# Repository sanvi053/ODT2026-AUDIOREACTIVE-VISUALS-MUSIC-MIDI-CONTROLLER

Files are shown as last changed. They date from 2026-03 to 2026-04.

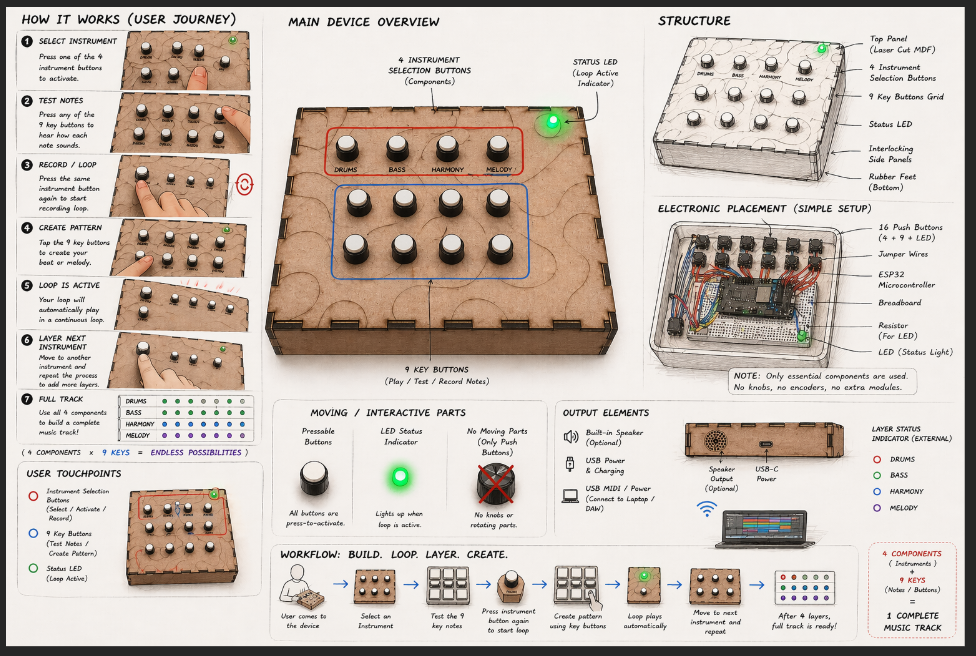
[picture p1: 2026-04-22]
images/Screenshot 2026-04-22 204658.png

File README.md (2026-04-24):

# Open Design and Technology  
## Final Project README

> **Project Weight:** 70%  
> **Team Size:** 2 students  
> **Project Duration:** 4 weeks  
> **Class Time Available:** 6 hours per class  
> **Total Time Available:** 48 effort-hours per team  
> **Project Type:** Playful, interactive, technology-based experience

---

# Before you begin

## Fork and rename this repository
After forking this repository, rename it using the format:

`ODT-2026-TeamName`

### Example
`ODT-2026-PixelWizards`

Do not keep the default repository name.

---

# How to use this README

This file is your team’s **working project document**.

You must keep updating it throughout the 4-week build period.  
By the final review, this README should clearly show:
- your idea,
- your planning,
- your design decisions,
- your technical process,
- your build progress,
- your testing,
- your failures and changes,
- your final outcome.

## Rules
- Fill every section.
- Do not delete headings.
- If something does not apply, write `Not applicable` and explain why.
- Add images, screenshots, sketches, links, and videos wherever useful.
- Update task status and weekly logs regularly.
- Use this file as evidence of process, not only as a final report.

---

# 1. Team Identity

## 1.1 Studio / Group Name
Audio Reactive Music MIDI Controller 

## 1.2 Team Members

| Name | Primary Role | Secondary Role | Strengths Brought to the Project |
|---|---|---|---|
| Manasvi D. | Electronics and Coding  | Physical Presentation  | Circuit Building  |
| Sanvi T. | Software manipulation  | Creating initial testing versions  | Musical understanding ` |

## 1.3 Project Title
Audio Reactive Music MIDI Controller 

## 1.4 One-Line Pitch
A MIDI Controller made from scratch that can help you create music using looping tracks and then see it corresponding to audio reactive visuals.  `

## 1.5 Expanded Project Idea
In 1–2 paragraphs, explain:
- what your project is,
- what kind of playful experience it creates,
- what makes it fun, curious, engaging, strange, satisfying, competitive, or delightful,
- what technologies are involved.

**Response:**  
Our project is an interactive music-making experience where users create and explore their own sound using a custom MIDI controller. They can switch between instruments, layer beats, and experiment with rhythms in an intuitive way, with no prior musical experience needed. The controller interfaces with Ableton Live, enabling real-time sound generation and flexible music creation. 

What makes it engaging is the instant audio-visual feedback: as users build their beats, their music is visualized in real time, making the process both satisfying and immersive. The project combines a custom MIDI controller, Ableton Live for music production, and TouchDesigner for dynamic visuals, blending physical interaction, sound, and visuals into a playful creative system. 

# 2. Philosophy Fit

## 2.1 Experience, Not Social Problem
This module does **not** require your project to solve a large social problem.

You are allowed to build:
- toys,
- games,
- interactive objects,
- playful machines,
- kinetic artifacts,
- humorous devices,
- strange but delightful experiences,
- things that are entertaining to use or watch.

## 2.2 What kind of experience are you creating?
Answer the following:
- What is the experience?
- What do you want the player or participant to feel?
- Why would someone want to try it again?

**Response:**  
This project places the user in the role of a DJ or live music performer, where their beats are paired with dynamic, captivating visuals to create a mini concert experience. It builds an immersive and playful environment where users feel in control of their performance and creative output. The experience encourages them to return, experiment with new beats, and discover how each change transforms the visuals in real time. 

## 2.3 Design Persona
Complete the sentence below:

> We are designing this project as if we are a small creative studio making a **[toy / game / playable object / interactive experience]** for **[children / teens / adults / classmates / exhibition visitors / mixed audience]**.

**Response:**  
We are designing this project as if we were a small design studio making an interactive experience for exhibition visitors to experiment with.  

---

# 3. Inspiration

## 3.1 References
List what inspired the project.

| Source Type | Title / Link | What Inspired You |
|---|---|---|
| Ed Sheeran Looping Pedal Live performances. | `[Link or title]` |Borrowed how he adds different tracks live to create a musical experience  |
|Live Audio-reactive visuals | `[Link or title]` |The act of live music controlling visuals |

## 3.2 Original Twist
What makes your project original?

**Response:**  
Combining live sets with visuals is not a common concept, and we decided to make music looping more accessible to non-professional artists.  

---

# 4. Project Intent

## 4.1 Core Interaction Loop
Describe the main loop of interaction.

Examples:
- press → launch → score → reset
- connect → control → observe → repeat
- turn → trigger → react → repeat
- move object → sensor detects → sound/light response → player reacts

**Response:**  
Press instrument button → Press same button again to activate loop recording → Press the keynotes to create beat → Press another instrument [if you want to add] → Repeat same steps → Once done creating the beat, press instrument buttons to clear recorded beat 

## 4.2 Intended Player / Audience

| Question | Response |
|---|---|
| Who is this for? | Exhibition visitors  |
| Age range | 12+|
| Solo or multiplayer |Solo|
| Expected duration of one round |3-4min|
| What should the player feel? |Immersed, creative, accomplished |
| Is explanation required before use? |Yes|

## 4.3 Player Journey
Describe exactly how a player will use the project.

1. **Approach:**  The player begins in front of a dormant visual display, with a custom music control unit placed on the table. 
2. **Start:** The interaction begins by creating the first looping track.
3. **First Action:** The player selects instruments using dedicated buttons to activate individual tracks.
4. **Main Interaction:** Beats and melodies are built layer by layer, with each track looping continuously in real time.
5. **System Response:** The audio plays and evolves through loops while the visuals dynamically respond and adapt to the sound. 
6. **Win / Lose / End Condition:** The session concludes once the complete music composition is formed, and the visuals fully respond to the final output.
7. **Reset:** A new round begins by clearing all active loops, allowing the user to start a fresh composition. 

## 4.4 Rules of Play
If your project is a game, list the rules clearly.

- `[Rule 1]`
- `[Rule 2]`
- `[Rule 3]`
- `[Rule 4]`

---

# 5. Definition of Success

## 5.1 Definition of “Playable”
Your project will be considered complete only if these conditions are met.

Music track is completed and looping 
The visuals react to the music in real time 

## 5.2 Minimum Viable Version
What is the smallest version of this project that still delivers the core experience?

One instrument track (ex. Piano) sends musical notes through buttons, and a basic visual reacts to them.  

## 5.3 Stretch Features
What features are nice to have but not essential?

Multiple instrument tracks (beyond the base instrument) 
Adding audio effects to beats created, i.e. reverb, delay, auto filter, etc. 
More advanced or detailed visual reactions in Touch Designer 
---

# 6. System Overview

## 6.1 Project Type
Check all that apply.

Electronics-based 
Mechanical 
Sound-based 
Screen/UI-based 
Fabricated structure
Installation / tabletop experience 
Other: Audioreactive Visuals 

## 6.2 High-Level System Description
Explain how the system works in simple terms.

Include:
- input,
- processing,
- output,
- physical structure,
- app interaction if any.

**Response:**  
When the user presses a button on the physical controller, the input is detected through an ESP32 running MicroPython in Thonny, using a BLE Keyboard library. This input is sent as keyboard signals to the computer. In Ableton Live, each sound or function is mapped to specific keyboard keys, so the received input triggers the corresponding instrument or sound. 

The system works on a simple mapping flow: physical button → ESP32 → keyboard signal → Ableton Live → audio output. The result is real-time sound generation based on user interaction 

## 6.3 Input / Output Map

| System Part | Type | What It Does |
|---|---|---|
|ESP32 / Controller | Processing  |Transmits input messages to output components  |
|LED / Sound / Display | Output  |LED- loop recording indicator; Sound- created music track; Display- Visual presentation of music track | 
|Mechanical Assembly  |Physical Action |NA|
---

# 7. Sketches and Visual Planning

## 7.1 Concept Sketch
Add an early sketch of the full idea.

**Insert image below:**  

Example:
```md

```

## 7.2 Labeled Build Sketch
Add a sketch with labels showing:
- structure,
- electronics placement,
- user touch points,
- moving parts,
- output elements.

**Insert image below:**  
`[Upload image and link here]`

## 7.3 Approximate Dimensions

| Dimension | Value |
|---|---|
| Length |9 in.|
| Width |7 in. |
| Height |3 in.|
| Estimated weight |500 gm |

---

# 8. Mechanical Planning

## 8.1 Mechanical Features
Check all that apply.

- [ ] Gears
- [ ] Pulleys
- [ ] Belt drives
- [ ] Linkages
- [ ] Hinges
- [ ] Shafts
- [ ] Springs
- [ ] Bearings
- [ ] Wheels
- [ ] Sliders
- [ ] Levers
- [ ] Not applicable

## 8.2 Mechanical Description
Describe the mechanism and what it is meant to do.

**Response:**  
`[Write here]`

## 8.3 Motion Planning
If something moves, explain:
- what moves,
- what causes the movement,
- how far it moves,
- how fast it moves,
- what could go wrong.

**Response:**  
`[Write here]`

## 8.4 Simulation / CAD / Animation Before Making
If your project includes mechanical motion, document the digital planning before fabrication.

| Tool Used | File / Link | What Was Tested |
|---|---|---|
| `[Fusion 360 / Tinkercad / other]` | `[Link or screenshot]` | `[What did you validate?]` |
| `[Tool]` | `[Link or screenshot]` | `[What did you validate?]` |

## 8.5 Changes After Digital Testing
What changed after the CAD, animation, or simulation stage?

**Response:**  
`[Write here]`

---

# 9. Electronics Planning

## 9.1 Electronics Used

| Component | Quantity | Purpose |
|---|---:|---|
|[ESP32] | 1 |Main controller|
|Push Button| 13 |Controlling the musical notes/beats and initiating/creating the loop|
|LED | 1 |Indicates if the loop recording has started|

## 9.2 Wiring Plan
Describe the main electrical connections.

**Response:**  
Buttons are connected various pins on ESP-32 
LED Bulb connected to ESP32 

## 9.3 Circuit Diagram
Insert a hand-drawn or software-made circuit diagram.

**Insert image below:**  
`[Upload image and link here]`

## 9.4 Power Plan

| Question | Response |
|---|---|
| Power source |USB|
| Voltage required |3V|
| Current concerns |Low power consumption overall, but unstable USB connections or insufficient power supply from some ports may cause intermittent disconnections of the ESP32. |
| Safety concerns |Accidentally soldering buttons incorrectly and damaging ESP-32 |

---

# 10. Software Planning

## 10.1 Software Tools

| Tool / Platform | Purpose |
|---|---|
|MicroPython Thonny |Thonny-Running Code and ESP32 |
|Ableton Live |MIDI controller outputs and instrumental track loop arrangement |
|Touchdesigner |Connecting music track components to visual manipulations |
|Adobe Illustrator |Used to create precise vector design files for laser cutting the MIDI controller setup|
|Rhino |Used to create precise vector design files for laser cutting the MIDI controller setup|

## 10.2 Software Logic
Describe what the code must do.

Include:
- startup behavior,
- input handling,
- sensor reading,
- decision logic,
- output behavior,
- communication logic,
- reset behavior.

**Response:**  
The software logic governs how the controller initializes, processes user inputs, and communicates with external software such as Ableton Live and TouchDesigner. 

Startup Behavior: 
When the system is powered on, the ESP32 initializes all GPIO pins for input (buttons) and output (LEDs). The Bluetooth module is activated, and the device begins advertising itself as a wireless input controller. Default states are assigned to all buttons and LEDs to ensure no unintended signals are sent during initialization. 

Input Handling: 
The system continuously scans the state of each button using a loop. Each button is configured with a pull-up resistor, meaning a press is detected when the signal changes from HIGH to LOW. The current state is compared with the previous state to detect valid press events (edge detection), preventing repeated triggering while a button is held down. 

Decision Logic: 
Based on the detected input, the system determines the appropriate action. For example: 

A single button press triggers a specific key or command.  

Sequential presses (such as first press, second press) are tracked using state variables.  

Conditional logic is used to control LED behavior (e.g., blinking sequence, steady ON state). 
This ensures that each interaction produces a predictable and controlled response.  

Output Behavior: 
Outputs are handled in two ways: 

Digital Output (LEDs): LEDs provide visual feedback based on system state, such as blinking during active phases or remaining ON to indicate a stable state.  

Software Output (Input Signals): The ESP32 sends keyboard/MIDI-like signals via Bluetooth, which are received by Ableton Live to trigger sounds, loops, or effects.  

Communication Logic: 
The controller communicates wirelessly via Bluetooth Low Energy (BLE). Input signals are transmitted as keyboard or MIDI messages. Ableton Live processes these inputs to generate audio, which is then routed internally to TouchDesigner using virtual audio drivers. This enables synchronized audio-visual output. 

Reset Behavior: 
The system resets under two conditions: 

Manual reset (power cycle): All states return to default, and Bluetooth reconnects.  

Logical reset: Certain interaction sequences (e.g., repeated button cycles) reset LED patterns and input states to prevent unintended looping or stuck states.  

This ensures stable operation during continuous use. 

## 10.3 Code Flowchart
Insert a flowchart showing your code logic.

Suggested sequence:
- start,
- initialize,
- wait for input,
- read input,
- decision,
- trigger output,
- repeat or reset,
- error handling.

**Insert image below:**  
`[Upload image and link here]`

## 10.4 Pseudocode
INITIALIZE Bluetooth keyboard with name "ESPMIDIMS" 

INITIALIZE LED as OUTPUT 

INITIALIZE performance buttons (A–L) as INPUT with pull-up resistors 

STORE last state of each performance key as HIGH 

INITIALIZE 4 control buttons as INPUT with pull-up resistors 

STORE last state of each control button as HIGH 

SET control state of each button = 0 

DEFINE control actions as: 

    Button 1 → [q, n, m] 

    Button 2 → [r, 2, 3] 

    Button 3 → [i, 4, 5] 

    Button 4 → [b, 6, 7] 

PRINT "Controller Ready" 

FUNCTION blink_LED: 

    REPEAT 4 times: 

        TURN LED ON 

        WAIT 0.5 seconds 

        TURN LED OFF 

        WAIT 0.5 seconds 

    TURN LED ON (stay ON) 

LOOP forever: 

    IF Bluetooth is connected: 

        // ------------------------- 

        // PERFORMANCE KEYS 

        // ------------------------- 

        FOR each key in performance keys: 

            READ current state 

            IF key is PRESSED (LOW) AND last state was NOT PRESSED (HIGH): 

                SEND corresponding key via Bluetooth 

                WAIT 40 ms 

            UPDATE last state 

        // ------------------------- 

        // CONTROL BUTTONS 

        // ------------------------- 

        FOR each control button (index i): 

            READ current state 

            IF button is PRESSED (LOW) AND last state was HIGH: 

                WAIT 50 ms (debounce) 

                IF still PRESSED: 

                    IF control state == 1: 

                        CALL blink_LED 

                    SELECT action from CONTROL_ACTIONS using control state 

                    SEND action via Bluetooth 

                    UPDATE control state: 

                        (state = (state + 1) mod 3) 

                    PRINT which button and action sent 

                    WAIT 150 ms 

            UPDATE last control state 

    WAIT 20 ms

---

# 11. MIT App Inventor Plan

## 11.1 Is an app part of this project?
- [ ] Yes
- [ ] No

If yes, complete this section.

## 11.2 Why is the app needed?
Explain what the app adds to the experience.

Examples:
- remote control,
- score tracking,
- mode selection,
- personalization,
- triggering effects,
- displaying data.

**Response:**  
`[Write here]`

## 11.3 App Features

| Feature | Purpose |
|---|---|
| `[Bluetooth connect button]` | `[Purpose]` |
| `[Score display]` | `[Purpose]` |
| `[Control button / slider / label]` | `[Purpose]` |

## 11.4 UI Mockup
Insert a sketch or screenshot of the app interface.

**Insert image below:**  
`[Upload image and link here]`

## 11.5 App Screen Flow

1. `[Step 1]`
2. `[Step 2]`
3. `[Step 3]`
4. `[Step 4]`

---

# 12. Bill of Materials

## 12.1 Full BOM

| Item | Quantity | In Kit? | Need to Buy? | Estimated Cost | Material / Spec | Why This Choice? |
|---|---:|---|---|---:|---|---|
| `[ESP32]` | `1` | `Yes` | `No` | `0` | `[Spec]` | `[Reason]` |
|Push Buttons|13|No (not the kind we needed) |Yes|Rs. 400| Not producing click sound when pressed  |Smoother interaction than provided push buttons|
|LED Bulb |1|Yes|0| `[Spec]` | `[Reason]` |
|Jumper Wire|35|No|0| `[Spec]` | `[Reason]` |

## 12.2 Material Justification
Explain why you selected your main materials and components.

Examples:
- Why acrylic instead of cardboard?
- Why MDF instead of 3D print?
- Why servo instead of DC motor?
- Why bearing instead of a plain shaft hole?

**Response:**  
We chose MDF for the base structure because it is strong, stable, and cost-effective compared to 3D printing large parts. It is easier to laser cut for flat structural components and provides good rigidity to hold the electronics securely. 

We used push buttons instead of more complex input components like rotary encoders or touch sensors because they are simple, reliable, and provide clear tactile feedback, making the interaction more intuitive for users. 

## 12.3 Items to Purchase Separately

| Item | Why Needed | Purchase Link | Latest Safe Date to Procure | Status |
|---|---|---|---|---|
|Push Buttons |Push Buttons  | NA (Nimesh Electronics)  |10th March |Received|

## 12.4 Budget Summary

| Budget Item | Estimated Cost |
|---|---:|
| Electronics | Rs. 400|
| Mechanical parts |NA|
| Fabrication materials |NA|
| Purchased extras |NA|
| Contingency |Rs.150|
| **Total** |Rs.550|

## 12.5 Budget Reflection
If your cost is too high, what can be simplified, removed, substituted, or shared?

**Response:**  
NA

---

# 13. Planning the Work

## 13.1 Team Working Agreement
Write how your team will work together.

Include:
- how tasks are divided,
- how decisions are made,
- how progress will be checked,
- what happens if a task is delayed,
- how documentation will be maintained.

**Response:**  
Team Working Strategy 

The project is executed through a collaborative approach where responsibilities are divided based on individual strengths, while still allowing overlap for support and flexibility. 

Task Division: 

Tasks are primarily divided according to expertise. Manasvi leads electronics and coding, focusing on circuit building and implementing the core logic. Sanvi leads software-related work, handling interaction with Ableton Live and TouchDesigner, along with initial testing and musical mapping. 

Both members support each other in secondary roles to ensure continuity and shared understanding of the system. 

Decision Making: 

Decisions are made collaboratively through discussion and testing. Ideas are evaluated based on functionality, user experience, and feasibility. In case of differing opinions, small prototypes or trials are created to test outcomes, and the most effective solution is selected. 

Progress Tracking: 

Progress is monitored through regular check-ins and testing sessions. Each module (electronics, coding, software integration) is tested individually and then combined to evaluate overall system performance. Milestones are set for key stages such as input detection, sound triggering, and audio-visual synchronization. 

Handling Delays: 

If a task is delayed, responsibilities are adjusted temporarily. The support owner assists in completing the pending task to maintain workflow continuity. Simpler alternatives or workarounds are also considered to avoid blocking the overall progress of the project. 

Documentation Maintenance: 

Documentation is primarily managed by Sanvi, with support from Manasvi. All stages of the project, including concept development, circuit design, code logic, and testing outcomes, are recorded regularly. Updates are made alongside development to ensure accuracy and completeness, rather than being compiled at the end. 

## 13.2 Task Breakdown

| Task ID | Task | Owner | Estimated Hours | Deadline | Dependency | Status |
|---|---|---|---:|---|---|---|
| T1 | `[Finalize concept]` | `Sanvi ` | `1 day ` | `7th April ` | `None` | `Finalize which software to use ` |
| T2 | `[Complete BOM]` | `Both ` | `Availabilty of shop timming ` | `10th April` | `T1` | `Placing porter from reliable shop ` |
| T3 | `[Test electronics]` | `Both ` | `24 hrs` | `15th April` | `T1` | `Testing how the electric components work along with code, and software ` |
| T4 | `[Build structure]` | `Both ` | `3 hrs` | `[20th April]` | `T1` | `Make laser cutting file and get it printed and assemble all parts together` |
| T5 | `[Write control code]` | `Manasvi` | `2 hrs` | `17th April` | `T3` | `Compling all libraries and testing code acc to condition required and debugging error ` |
| T6 | `[Integrate system]` | `Both` | `1 h` | `19th April` | `T4, T5` | `Having a checklist of steps to verify if all steps have been achieved in correct order ` |
| T7 | `[Playtest]` | `Both` | `2` | `30 mins ` | `T6` | `Doing multiple trials to figure out any difficulty if faces` |
| T8 | `[Refine and document]` | `Sanvi ` | `6hr` | `13rd April` | `T7` | `Take videos along the process throughout` |

## 13.3 Responsibility Split

| Area | Main Owner | Support Owner |
|---|---|---|
| Concept and gameplay | Sanvi |Manasvi |
| Electronics |Manasvi |Sanvi |
| Coding |Manasvi |Sanvi |
| Software (Ableton Live & Touchdesigner) |Sanvi| Manasvi|
| Testing |Both|Both |
| Documentation |Sanvi  |Manasvi |

---

# 14. Weekly Milestones

## 14.1 Four-Week Plan

### Week 1 — Plan and De-risk
Expected outcomes:
- [ ] Idea finalized
- [ ] Core interaction decided
- [ ] Sketches made
- [ ] BOM completed
- [ ] Purchase needs identified
- [ ] Key uncertainty identified
- [ ] Basic feasibility tested

### Week 2 — Build Subsystems
Expected outcomes:
- [ ] Electronics tests completed
- [ ] CAD / structure planning completed
- [ ] App UI started if needed
- [ ] Mechanical concept tested
- [ ] Main subsystems partially working

### Week 3 — Integrate
Expected outcomes:
- [ ] Physical body built
- [ ] Electronics integrated
- [ ] Code connected to hardware
- [ ] App connected if required
- [ ] First playable version exists

### Week 4 — Refine and Finish
Expected outcomes:
- [ ] Technical bugs reduced
- [ ] Playtesting completed
- [ ] Improvements made
- [ ] Documentation completed
- [ ] Final build ready

## 14.2 Weekly Update Log

| Week | Planned Goal | What Actually Happened | What Changed | Next Steps |
|---|---|---|---|---|
| Week 1 | `Complete the mechanisms of first idea` | `Idea changes and testing began` | `The idea ` | `Continue to test the idea ` |
| Week 2 | `Complete full testing ` | `Full testing completed ` | `Nothing ` | `Start final circuit and code` |
| Week 3 | `First working prototype ` | `Half made first working prototype ` | `Completion not as planned ` | `Complete the prototype ` |
| Week 4 | `Final product, fix mistakes of prototype ` | `Finished product made ` | `Nothing ` | `Laser cutting to make final product ` |

---

# 15. Risks and Unknowns

## 15.1 Risk Register

| Risk | Type | Likelihood | Impact | Mitigation Plan | Owner |
|---|---|---|---|---|---|
| `[Example: Bluetooth disconnects]` | `Technical` | `Medium` | `High` | `[Fallback interaction / simplify connection flow]` | `[Name]` |
| `[Example: Structure breaks during play]` | `Mechanical` | `Medium` | `High` | `[Reinforce joints / change material]` | `[Name]` |
| `[Risk]` | `[Technical / Material / Time / Gameplay]` | `[Low/Medium/High]` | `[Low/Medium/High]` | `[Plan]` | `[Name]` |
| `[Risk]` | `[Type]` | `[Low/Medium/High]` | `[Low/Medium/High]` | `[Plan]` | `[Name]` |

## 15.2 Biggest Unknown Right Now
What is the single biggest uncertainty in your project at this stage?

**Response:**  
` Whether Ableton live and Touch-designer would connect with each other and the circuit. `

---

# 16. Testing and Playtesting

## 16.1 Technical Testing Plan

| What Needs Testing | How You Will Test It | Success Condition |
|---|---|---|
| `[Bluetooth connection]` | `Power on the ESP32 controller and connect it to the laptop through BLE multiple times. ` | `Device connects successfully within a few seconds and remains stable without disconnection during use. ` |
| `[Mechanism movement]` | `Rotate all potentiometer knobs and press all buttons repeatedly to check smooth movement and physical reliability. ` | `Buttons respond correctly, and no loose or stuck components occur. ` |
| `Mapping controls Ableton Live and ableton live is manipulating touchdesigner visuals ` | `[Method]` | `Every button/control input is received in Ableton Live, visuals in TouchDesigner respond correctly in real time, and no noticeable lag or missed triggers occur. ` |

## 16.2 Playtesting Plan

| Question | How You Will Check |
|---|---|
| Do players understand what to do? | `Observe first-time players using the controller without explanation and note if they can start interacting correctly within the first minute` |
| Is the interaction satisfying? | `Ask players to use the buttons, then gather feedback on responsiveness, comfort, and enjoyment through a short questionnaire. ` |
| Do players want another turn? | `After one session, ask if they would like to play/use it again or observe if they voluntarily continue interacting. ` |
| Is the challenge balanced? | `Test with different users and note whether tasks feel too easy, too confusing, or appropriately engaging.` |
| Is the response clear and immediate? | `Observe whether users notice instant feedback from each button press or knob movement and ask if any delays caused confusion.` |

## 16.3 Testing and Debugging Log

| Date | Problem Found | Type | What You Tried | Result | Next Action |
|---|---|---|---|---|---|
| `10/04/2026 ` | `Connecting ESP32 to Ableton Live via WiFi ` | `Technical ` | `Attempted WiFi-based communication using network libraries to send signals from ESP32 ` | `Failed ` | `Switched approach to Bluetooth (BLE keyboard) for simpler and more stable connection ` |
| `12/04/2026 ` | `Delay/latency in triggering sounds ` | `Technical ` | `Reduced delay values in code and optimized loop timing ` | `Partly ` | `Further optimize code and explore MIDI protocol instead of keyboard input ` || `14/04/2026 ` | `Buttons triggering multiple times on single press ` | `Technical ` | `Implemented state tracking (last state vs current state) and added debounce delay ` | `Worked ` | `Fine-tune delay timing for better responsiveness` || `16/04/2026 ` | `Audio not routing to TouchDesigner ` | `Technical ` | `Configured virtual audio cable and checked system sound settings ` | `Partly ` | `Recalibrate audio input levels and verify correct device selection` || `18/04/2026 ` | `Visuals not syncing properly with audio ` | `Technical / UI ` | `Adjusted audio analysis parameters and experimented with different operators in TouchDesigner` | `Partly` | `Improve BPM syncing and refine audio-reactive mapping` || `19/04/2026 ` | `LED not reflecting correct interaction state` | `Technical ` | `Modified logic to include multi-step state tracking and blinking function ` | `Worked ` | `Enhance feedback with more patterns if needed ` || `20/04/2026 ` | `Testing knobs to add audio effects ` | `Technical / UI ` | `Explored using analog inputs and mapping them in Ableton Live` | `Failed` | `Revisit after stabilizing button inputs; consider adding potentiometers later` || `21/04/2026 ` | `Bluetooth disconnection issues ` | `Technical ` | `Retested BLE connection and simplified code to reduce load ` | `Partly` | `Further test stability over longer durations` || `22/04/2026 ` | `Button layout not comfortable to use ` | `UI / Gameplay` | `Rearranged button positions on enclosure` | `Worked` | `Refine spacing and ergonomics in next iteration ` |

## 16.4 Playtesting Notes

| Tester | What They Did | What Confused Them | What They Enjoyed | What You Will Change |
|---|---|---|---|---|
| `[Peer / friend / classmate]` | `Following our instructions and making music ` | `The logic of instrument select -> record -> clear is confusing ` | `Music making process and audiovisual output` | `More indication for the processes needed` |
| `[Peer / friend / classmate]` | `Pressed wrong keynotes and wanted to try redoing it ` | `Pressed button twice and code was not supporting this issue ` | `Having a compilation of various musical components and visual reacting to it` | `Make code capable to handle complex scenarios` |

---

# 17. Build Documentation

## 17.1 Fabrication Process
Describe how the project was physically made.

Include:
- cutting,
- 3D printing,
- assembly,
- fastening,
- wiring,
- finishing,
- revisions.

**Response:**  
`Physical Making Process 

The project was developed as a functional prototype using simple fabrication and assembly methods, with a focus on usability and iterative improvement. 

Cutting: 
MDF sheets were measured and cut to size to create the outer enclosure. Openings were carefully cut on the top surface to fit the push buttons, ensuring proper alignment and spacing for comfortable interaction. 

Assembly: 
The MDF outer box was assembled to house the components. The ESP32, buttons, and LED were positioned inside the enclosure, with the buttons aligned through the pre-cut holes on the top panel for easy access during use. 

Fastening: 
The MDF panels were designed with interlocking grooves, allowing them to fit into each other without the need for additional fasteners. This slot-fit construction provided structural stability while also making it easier to assemble and disassemble the enclosure when required. 

Wiring: 
Connections were made between the ESP32, buttons, and LED to complete the circuit. Pull-up configurations were used for stable input readings. Care was taken to organize the internal connections to reduce interference and ensure reliable performance. 

Finishing: 
Basic finishing was done on the MDF surface to smooth edges and improve handling. The focus remained on functionality, but the enclosure also helped make the prototype more presentable and easier to use compared to an open setup. 

Revisions: 
Multiple revisions were made throughout the process. The size and placement of button cutouts were adjusted for better ergonomics, and the internal layout was modified to improve accessibility and stability. The enclosure design evolved alongside the electronics to better support both functionality and user interaction. `

## 17.2 Build Photos
Add photos throughout the project.

Suggested images:
- early sketch,
- prototype,
- electronics testing,
- mechanism test,
- app screenshot,
- final build.

[
Photos](https://drive.google.com/drive/folders/1VnE3HjinkveTJ-CehP7-WkfJnld4jkN7?usp=sharing)

# 18. Final Outcome

## 18.1 Final Description
Describe the final version of your project.

**Response:**  
`Final Version of the Project 

The final version of the project is a functional prototype of a DIY wireless MIDI-style controller that enables real-time interaction between sound and visuals. The system consists of an ESP32-based hardware interface with multiple push buttons and an LED feedback system, connected wirelessly to a computer via Bluetooth. 

The controller is programmed to send key-based input signals, which are mapped in Ableton Live to trigger sounds, loops, and effects. These audio outputs are internally routed to Touch-Designer, where they are used to generate responsive visuals. This creates a synchronized audio-visual experience controlled entirely through physical interaction. 

The interface includes two types of inputs: 

Performance keys, which trigger immediate sound outputs for live interaction  

Control buttons, which cycle through multiple states and actions, allowing layered control over different functions  

An LED is integrated to provide visual feedback, including blinking patterns and steady states, helping the user understand system responses during interaction. 

The system successfully demonstrates: 

Wireless control using Bluetooth  

Real-time input detection and response  

Multi-state interaction logic  

Integration between hardware, audio software, and visual output  

While the current build uses a breadboard-based setup, it effectively validates the concept of a low-cost, customizable controller for live audio-visual performance. The final prototype emphasizes interactivity, responsiveness, and the seamless connection between physical input and digital output.`

## 18.2 What Works Well
- `The project performs reliably as a real-time interactive system, successfully connecting physical inputs to both sound and visuals. The button inputs are responsive and consistently detected, allowing smooth triggering of mapped functions in Ableton Live. This makes live interaction feel immediate and controllable. `
- `The multi-state control logic works effectively, especially in the control buttons that cycle through different actions. This allows more functionality without increasing hardware complexity, making the controller efficient and flexible. `
- `The integration between Ableton Live and Touch-Designer also works well. Audio routing and signal flow are stable, enabling visuals to respond to sound in real time, which strengthens the overall audio-visual experience. `
- `The LED feedback system is simple but effective, clearly indicating system states such as active modes or transitions. This helps the user understand what is happening without needing to look at the screen constantly. `
- `Finally, the overall concept of a low-cost, DIY controller is successfully achieved. The system demonstrates that a functional and expressive performance tool can be built using accessible components, while still allowing room for customization and future expansion. `

## 18.3 What Still Needs Improvement
- `The code flow of the instrumental components (select-record-clear) was not always foolproof.`
- `Making the overall project more self-explanatory.`
- `Giving better feedback on the status if the buttons (clicked/not clicked)`

## 18.4 What Changed From the Original Plan
How did the project change from the initial idea?

**Response:**  
`Initially, the plan was to connect the ESP32 directly to Ableton Live using software such as loopMIDI, MIDI-OX, and Hairless MIDI. However, due to compatibility issues and the outdated nature of these tools, the approach was revised. Instead, the project shifted to using the BLE Keyboard library on the ESP32, allowing key inputs to be mapped directly within Ableton Live for a more reliable and efficient connection. `

---

# 19. Reflection

## 19.1 Team Reflection
What did your team do well?  
What slowed you down?  
How well did you manage time, tasks, and responsibilities?

**Response:**  
`Figuring out the method to connect buttons to the software took some time as we had to juggle between new and outdated methods alike, only relying on online tutorials and AI prompts. We played with our strengths and trusted the other teammate to complete the delegated and planned task properly.`

## 19.2 Technical Reflection
What did you learn about:
- electronics,
- coding,
- mechanisms,
- fabrication,
- integration?

**Response:**  
`Keyboard keys mapping to buttons  

We developed a better understanding of structured logic, especially real-time input handling using loops and condition checks. Concepts like state tracking, edge detection, and timing delays were important in making the system responsive and stable 

We also learned how to implement Bluetooth-based communication and map physical inputs to digital outputs. `

## 19.3 Design Reflection
What did you learn about:
- designing for play,
- delight,
- clarity,
- physical interaction,
- player understanding,
- iteration?

**Response:**  
`Music and loop making 

Designing for variability (differnt outcomes of visuals possible) `

## 19.4 If You Had One More Week
What would you improve next?

**Response:**  
`Create an indicator for when the instrumental component buttons are pressed 

The Bluetooth-based communication introduces slight delays and occasional instability. Moving from keyboard emulation to a true MIDI protocol and optimizing the connection would improve responsiveness, especially during live performance. 

Adding analog inputs such as knobs or sliders would allow more expressive control over parameters like volume, filters, and effects in Ableton Live, making the interaction more dynamic. `

---

# 20. Final Submission Checklist

Before submission, confirm that:
- [ ] Team details are complete
- [ ] Project description is complete
- [ ] Inspiration sources are included
- [ ] Player journey is written
- [ ] Sketches are added
- [ ] BOM is complete
- [ ] Purchase list is complete
- [ ] Budget summary is complete
- [ ] Mechanical planning is documented if applicable
- [ ] App planning is documented if applicable
- [ ] Code flowchart is added
- [ ] Task breakdown is complete
- [ ] Weekly logs are updated
- [ ] Risk register is complete
- [ ] Testing log is updated
- [ ] Playtesting notes are included
- [ ] Build photos are included
- [ ] Final reflection is written

---

# 21. Suggested Repository Structure

```text
project-repo/
├── README.md
├── images/
│   ├── concept-sketch.jpg
│   ├── labeled-sketch.jpg
│   ├── circuit-diagram.jpg
│   ├── ui-mockup.jpg
│   ├── prototype-1.jpg
│   └── final-build.jpg
├── code/
│   ├── main.py
│   ├── test_code.py
│   └── notes.md
├── cad/
│   ├── models/
│   └── screenshots/
└── docs/
    ├── references.md
    └── extra-notes.md
```

---

# 22. Instructor Review

## 22.1 Proposal Approval
- [ ] Approved to proceed
- [ ] Approved with changes
- [ ] Rework required before proceeding

**Instructor comments:**  
`[Instructor fills this section]`

## 22.2 Midpoint Review
`[Instructor fills this section]`

## 22.3 Final Review Notes
`[Instructor fills this section]`

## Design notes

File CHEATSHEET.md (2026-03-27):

# GitHub Cheat Sheet
## Open Design and Technology Final Project

This file is a quick guide for working in your project repository.

---

# 1. First setup

## Fork this repository
1. Click **Fork**.
2. Rename your fork using this format:

`ODT-2026-TeamName`

### Example
`ODT-2026-PixelWizards`

## Do not do this
- Do not keep the default repo name.
- Do not upload everything at the very end.
- Do not delete headings from the main `README.md`.

---

# 2. Folder structure

Your repository should look like this:

```text
project-repo/
├── README.md
├── CHEATSHEET.md
├── images/
├── code/
├── cad/
└── docs/
```

## What goes where

| Folder | What to put inside |
|---|---|
| `images/` | Sketches, photos, screenshots, UI mockups, circuit diagrams |
| `code/` | Main code files, test code, code notes |
| `cad/` | CAD files, STL files, design exports, screenshots |
| `docs/` | Extra notes, reference links, playtest notes |

---

# 3. Uploading files

## Upload an image
1. Open the repository.
2. Open the `images` folder.
3. Click **Add file**.
4. Click **Upload files**.
5. Drag your image into the browser.
6. Scroll down and click **Commit changes**.

## Upload code
1. Open the `code` folder.
2. Click **Add file**.
3. Click **Upload files**.
4. Upload your `.py`, `.ino`, `.txt`, or `.md` files.
5. Click **Commit changes**.

## Good file names
Use clean file names such as:
- `concept-sketch.jpg`
- `ui-mockup.png`
- `prototype-v1.jpg`
- `main.py`
- `ble-test.py`

## Avoid bad file names
Avoid names like:
- `IMG_4587.jpg`
- `finalfinalrealone.png`
- `new code latest.py`

---

# 4. Adding Images to your README

**Rule #1:** You must upload your image file to the `images/` folder *before* you can link it in the README. 

**Rule #2:** File names are case-sensitive. `Image.JPG` is not the same as `image.jpg`.

I have placed a file called `sample_image_1.jpg` and `sample_image_2.jpg` in your `images/` folder. Copy and paste the 4 examples below into your README to see how they work!

---

### Example 1: The Basic Image (Markdown)
Use this for a standard, full-size image.

```html
<img src="images/sample_image_1.jpg" width="400">

```

### Example 2: Resizing an Image (HTML)
Phone photos are often massive. If an image takes up your whole screen, switch to HTML to control the width. *(Change `width="400"` to whatever number looks best).*

```html
<img src="images/sample_image_1.jpg" width="400">
```


### Example 3: Centering an Image
If you want your documentation to look clean and professional, you can center the image on the page using this HTML block.

```html
<p align="center">
  <img src="images/sample_image_1.jpg" width="400">
</p>
```
<p align="center">

</p>

### Example 4: Side-by-Side Images
Want to show the front and back of your build, or your app next to your hardware? Just put two HTML image tags on the exact same line with a space between them. 

```html
<img src="images/sample_image_1.jpg" width="300"> <img src="images/sample_image_2.jpg" width="300">
```
 

*(Note: Ensure their combined width is less than ~800 so they fit next to each other on most screens).*

---

### Quick Troubleshooting: "My image is just showing a broken link icon!"
If your image doesn't load when you click the **Preview** tab, check these 3 things:
1. **Path:** Did you include `images/` before the file name?
2. **Spelling/Spaces:** Does the code match your file name exactly? (Avoid spaces in file names—use dashes `-` instead).
3. **Extension:** Did you write `.png` but the file is actually a `.jpg`?
# 5. Editing README

## To edit the README directly on GitHub
1. Open `README.md`.
2. Click the pencil icon.
3. Add or update your content.
4. Scroll down.
5. Write a short commit message.
6. Click **Commit changes**.

## Update this file every week
You should keep updating:
- task status,
- BOM,
- sketches,
- testing logs,
- playtesting notes,
- photos,
- weekly progress.

---

# 6. Creating folders on GitHub

GitHub does not create truly empty folders, so a folder is usually created by making a file inside it. [web:54][web:58]

## To create a folder from the GitHub website
1. Click **Add file**.
2. Click **Create new file**.
3. Type a path like:

```text
images/.gitkeep
```

4. Commit the change.

You can do the same for:
- `code/.gitkeep`
- `cad/.gitkeep`
- `docs/.gitkeep`

Typing a file path with a `/` is the usual way to create a folder in GitHub’s web interface. [web:54][web:57]

---

# 7. Commit message guide

Use short commit messages that explain what changed.

## Good examples
- `Added BOM and budget`
- `Uploaded concept sketch`
- `Updated week 2 progress`
- `Added BLE test code`
- `Uploaded final prototype photos`

## Bad examples
- `update`
- `stuff`
- `changes`
- `final`

---

# 8. Team workflow

## Suggested rule
At the end of every class, do these 4 things:
1. Upload new photos.
2. Update task status.
3. Add what worked and what failed.
4. Commit changes before leaving class.

## Team habit
One person can lead the build update for the day, but both team members are responsible for checking that the repo stays current.

---

# 9. If you make a mistake

## If you uploaded the wrong file
- Upload the correct file.
- Delete the wrong file.
- Write a clear commit message.

## If you deleted something important
- Tell your teammate immediately.
- Check the file history.
- Restore it from an earlier version if needed.

## If your README looks broken
- Check for missing `#`, `|`, or backticks.
- Preview before committing.

---

# 10. Minimum expectation each week

By the end of each week, your repository should show visible progress.

## Week 1
- Idea
- Sketch
- Inspiration
- BOM
- Task plan

## Week 2
- Tests
- CAD or structure progress
- Code or app progress
- Photos

## Week 3
- Integrated prototype
- Technical debugging
- Gameplay/playtesting notes

## Week 4
- Final build
- Final documentation
- Reflection
- Clean repo

---

# 11. Final reminder

This repository is not just a place to submit work.

It is:
- your project tracker,
- your evidence of process,
- your design notebook,
- your technical log,
- your final documentation.

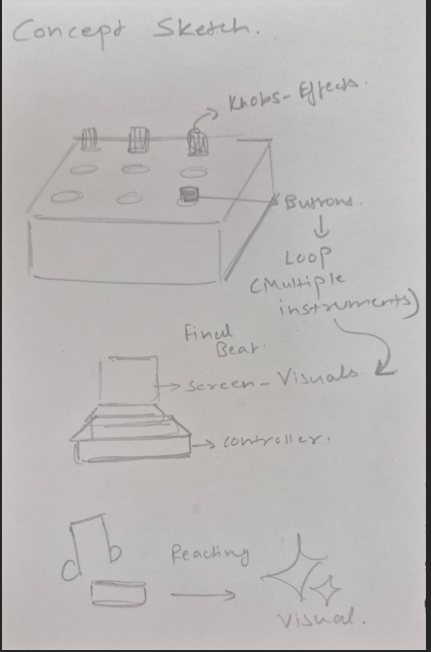
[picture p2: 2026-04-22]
images/Screenshot 2026-04-22 204614.png

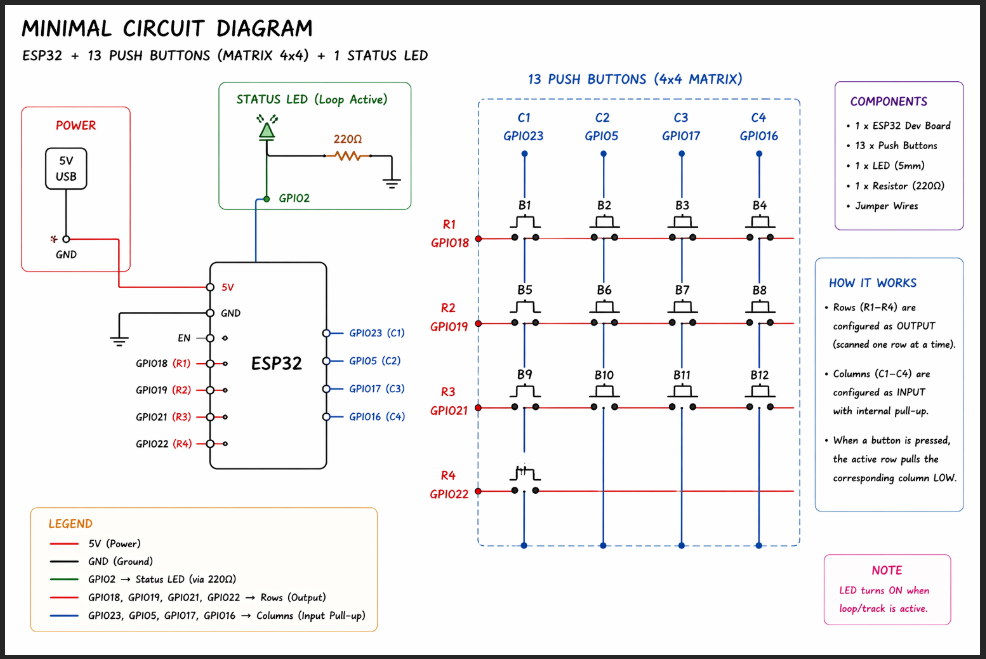
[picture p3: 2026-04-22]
images/Screenshot 2026-04-22 204855.png

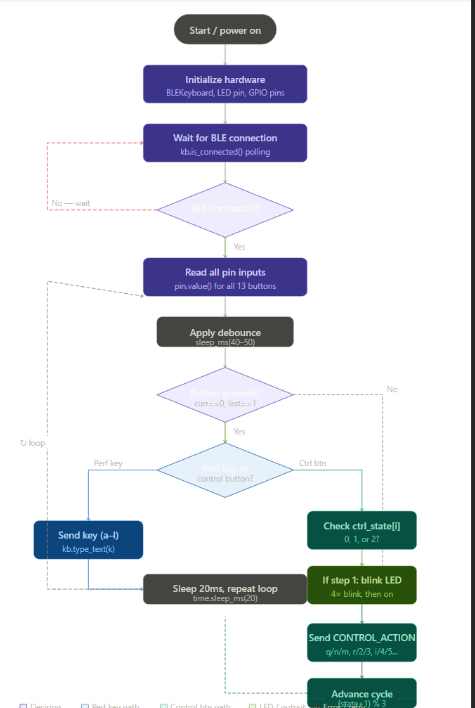
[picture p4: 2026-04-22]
images/Screenshot 2026-04-22 204800.png

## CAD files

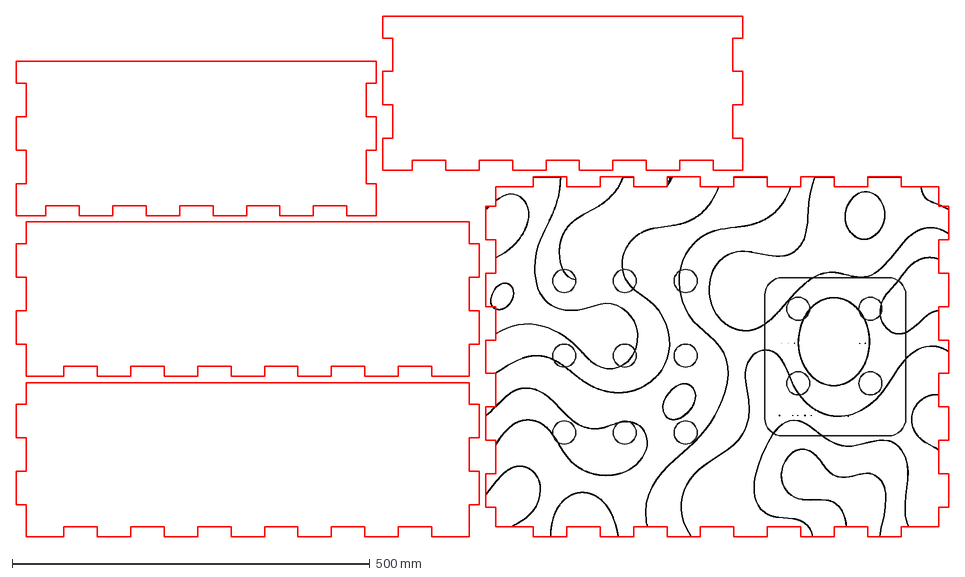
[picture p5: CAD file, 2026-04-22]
cad/sanvi v1.dxf
1304.5 x 728.5 mm

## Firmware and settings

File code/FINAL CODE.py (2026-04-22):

from ble_keyboard import BLEKeyboard
from machine import Pin
import time

kb = BLEKeyboard("ESPMIDIMS")

# -------------------------
# LED
# -------------------------
led = Pin(2, Pin.OUT)

# -------------------------
# PERFORMANCE KEYS (A–L)
# -------------------------
key_map = {
    "a": Pin(18, Pin.IN, Pin.PULL_UP),
    "s": Pin(5, Pin.IN, Pin.PULL_UP),
    "d": Pin(4, Pin.IN, Pin.PULL_UP),
    "f": Pin(22, Pin.IN, Pin.PULL_UP),
    "g": Pin(21, Pin.IN, Pin.PULL_UP),
    "h": Pin(19, Pin.IN, Pin.PULL_UP),
    "j": Pin(26, Pin.IN, Pin.PULL_UP),
    "k": Pin(27, Pin.IN, Pin.PULL_UP),
    "l": Pin(14, Pin.IN, Pin.PULL_UP),
}

last_state = {k: 1 for k in key_map}

# -------------------------
# CONTROL BUTTONS
# -------------------------
control_pins = [
    Pin(12, Pin.IN, Pin.PULL_UP),
    Pin(13, Pin.IN, Pin.PULL_UP),
    Pin(32, Pin.IN, Pin.PULL_UP),j
    Pin(33, Pin.IN, Pin.PULL_UP),
]

last_ctrl = [1, 1, 1, 1]
ctrl_state = [0, 0, 0, 0]

# -------------------------
# ACTIONS
# -------------------------
CONTROL_ACTIONS = [
    ['q', 'n', 'm'],
    ['r', '2', '3'],
    ['i', '4', '5'],
    ['b', '6', '7'],
]

print("Ableton controller ready")

# -------------------------
# LED BLINK FUNCTION
# -------------------------
def blink_led():
    for _ in range(4):
        led.on()
        time.sleep(0.5)
        led.off()
        time.sleep(0.5)
    led.on()  # stays ON always

# -------------------------
# MAIN LOOP
# -------------------------
while True:
    if kb.is_connected():

        # =====================
        # PERFORMANCE KEYS
        # =====================
        for k, pin in key_map.items():
            curr = pin.value()

            if curr == 0 and last_state[k] == 1:
                kb.type_text(k)
                time.sleep_ms(40)

            last_state[k] = curr

        # =====================
        # CONTROL BUTTONS
        # =====================
        for i, pin in enumerate(control_pins):
            curr = pin.value()

            if curr == 0 and last_ctrl[i] == 1:

                time.sleep_ms(50)
                if pin.value() == 0:

                    # 🔴 BLINK ONLY on 2nd step (step 1)
                    if ctrl_state[i] == 1:
                        blink_led()

                    # 🎹 send key
                    action = CONTROL_ACTIONS[i][ctrl_state[i]]
                    kb.type_text(action)

                    # 🔁 advance cycle (0 → 1 → 2 → 0)
                    ctrl_state[i] = (ctrl_state[i] + 1) % 3

                    print("Instrument", i+1, "Sent:", action)

                    time.sleep_ms(150)

            last_ctrl[i] = curr

    time.sleep_ms(20)
